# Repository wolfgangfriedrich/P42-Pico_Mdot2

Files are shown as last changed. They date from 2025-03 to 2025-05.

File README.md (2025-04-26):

# P42 Pico M.2

A RPi Pico RP2350A microcontroller board in m.2 3024 form factor with A and E key. The m.2 interface has USB, UART, I2C and control IO connectivity. Voltage levels for the m.2 specification are obeyed as some of the interfaces run on 1.8 V. Externally, +3.3 V, GND, the SWD interface and 16 IOs are accessible on castellated pins. A footprint for a QWIIC connector is on the top side of the board, not populated to have the board as low profile as possible. Power rail LEDs and a user controlled LED is on board, as well as a solder bridge for configuration options. Bottom side has a micro-SD card slot for data storage.
A microcontroller could give any host computer flexible and excellent real-time IO and data processing capabilities. The RPi Pico with its programmable PIO interface has excellent timing resolution. 

### Pre-order campaign on Lectronz https://lectronz.com/campaigns/pre-order-p42-pico2-m-2

Full Feature List:
*	M.2 2230-D5-AE card (22 mm x 30 mm; D5 = 1.5mm on top and bottom side violated by the QWIIC connector and the bottom SD card holder; A and E key)
*	Used interfaces on the M.2: USB, UART, I2C, ALERT, WAKE, DISABLE1/2, LED 1/2, VENDOR_DEFINED
*	1.8V regulator for level-shifters
*	Power LEDs for 3.3 V and 1.1 V
*	RP2040/RP2350 peripherals: 2 MB Flash, SWD debug access, RESET and BOOTSEL button, 
*	QWIIC connector, 1 LED, 1 solder bridge for configuration, 16 GPIOs on castellated pins
*	castellated pins on 25.4 mm/0.1" raster (almost with a 22 mm board)
*	optional uSD card holder on the bottom side
*	optional pull-down resistors on castellated IOs to mitigate the E9 Erratum

Main Components
*	Microcontroller RaspberryPi RP2350A
*	16Mbit QSPI Flash W25Q16
*	12 MHz Crystal SMD_3225-4Pin_3.2x2.5mm
*	MicroSD card holder Molex 104031-0811
*	1.8V-3.3V High Speed level shifter Texas Instruments TXS0102DQM

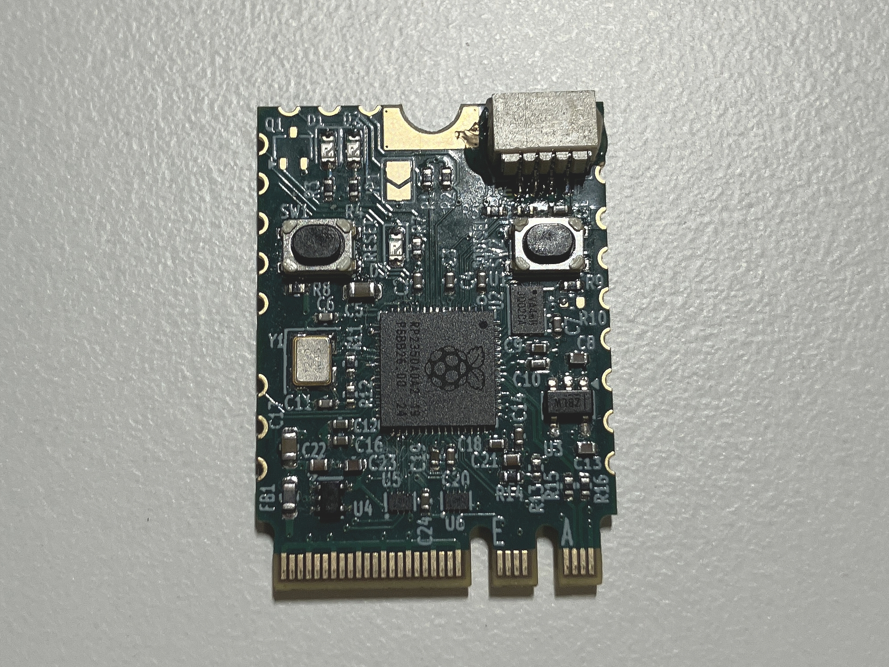
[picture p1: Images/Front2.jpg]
Board Front side


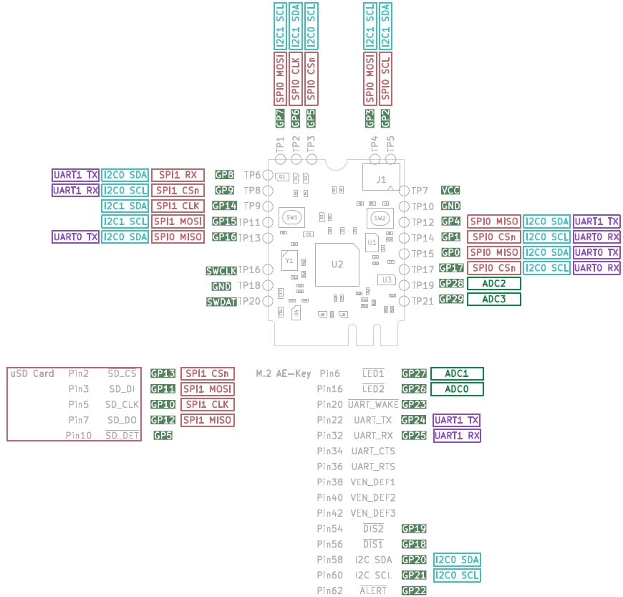
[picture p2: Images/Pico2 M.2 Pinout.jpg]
Board Pinout


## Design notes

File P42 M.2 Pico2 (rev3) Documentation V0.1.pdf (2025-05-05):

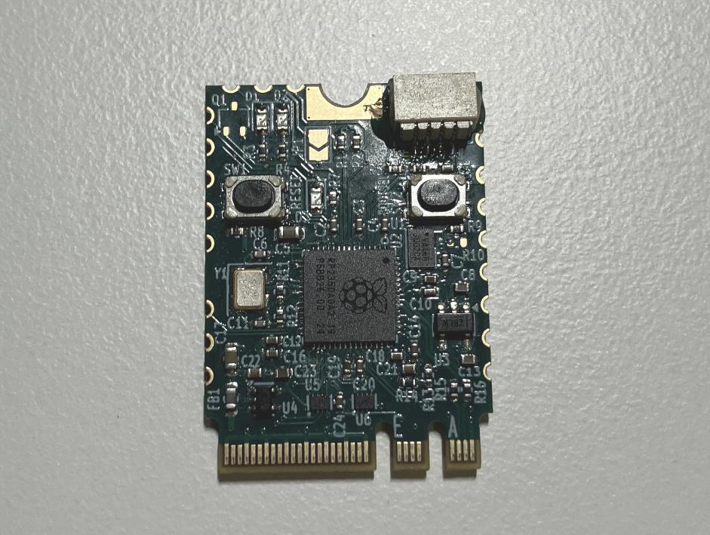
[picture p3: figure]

# P42 Pico2 M.2 Rev 3

Designed by Pier42 Electronics Design Wolfgang Friedrich
Released under CERN Open Hardware License Version 2 - Weakly Reciprocal https://lectronz.com/stores/pier42designhttps://www.tindie.com/stores/pier42/https://hackaday.io/project/199091-rp2040-rp2350-m2-picohttps://github.com/wolfgangfried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

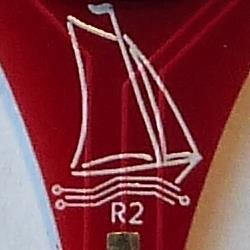
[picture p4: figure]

# Table of Contents

# Introduction

A RPi Pico2 RP2350A microcontroller board in m.2 3024 size form factor with A and E key. The m.2 interface has USB, UART, I2C and control IO connectivity. Voltage levels for the m.2 specification are obeyed as some of the interfaces run on 1.8 V. Externally, +3.3 V, GND, the SWD interface and 16 IOs are accessible on castellated pins. A footprint for a QWIIC connector is on the top side of the board, not populated to have the board as low profile as possible. Power rail LEDs and a user controlled LED is on board, as well as a solder bridge for configuration options. Bottom side has a micro-SD card slot for data storage.
A microcontroller could give any host computer flexible and excellent real-time IO and data processing capabilities. The RPi Pico with its programmable PIO interface has excellent timing resolution.

Full Feature List:
- M.2 2230-D5-AE card (22 mm x 30 mm; D5 = 1.5mm on top and bottom side violated by the QWIIC connector and the bottom SD card holder; A and E key)
- Used interfaces on the M.2: USB, UART, I2C, ALERT, WAKE, DISABLE1/2, LED 1/2, VENDOR_DEFINED
- 1.8V regulator for level-shifters
- Power LEDs for 3.3 V and 1.1 V
- RP2040/RP2350 peripherals: 2 MB Flash, SWD debug access, RESET and BOOTSEL button,
- QWIIC connector, 1 LED, 1 solder bridge for configuration, 16 GPIOs on castellated pins
- castellated pins on 25.4 mm/0.1" raster (almost with a 22 mm board)
- optional µSD card holder on the bottom side
- optional pull-down resistors on castellated IOs to mitigate the E9 Erratum

Main Components
- Microcontroller RaspberryPi RP2350A
- 16Mbit QSPI Flash W25Q16
- 12 MHz Crystal SMD_3225-4Pin_3.2x2.5mm
- MicroSD card holder Molex 104031-0811
- 1.8V-3.3V High Speed level shifter Texas Instruments TXS0102

# Hardware

The board is a standard M.2 2230-D5-AE card (22 mm x 30 mm; 0.8mm thickness; D5 = 1.5mm on top and bottom side violated by the QWIIC connector and the bottom SD card holder; A and E key). The M.2 card edge connector is ENIG plated. Castellated pins are on a 2.54mm (0.1”) raster per side. The mechanical constriants did not work out to have all pins on a global 2.54mm (0.1”) raster.

## Pico2 M.2 Pinout

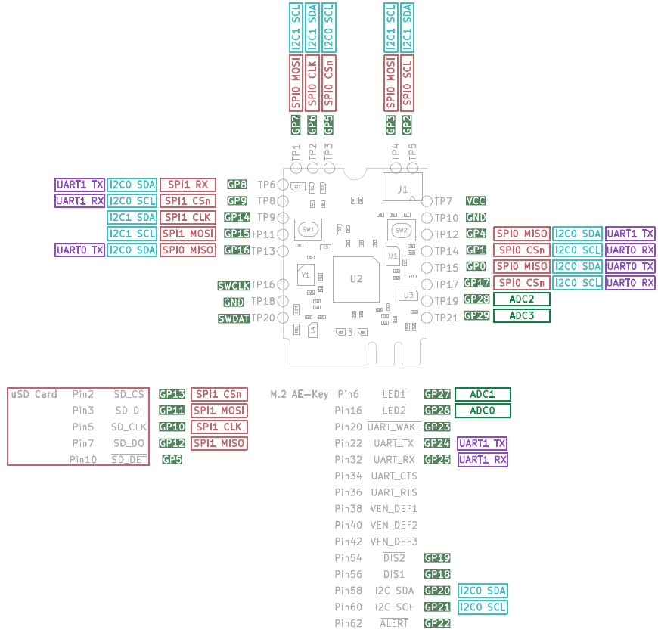
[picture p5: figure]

## M.2 Port Interface

I2C interface on pins 60 (SCL) and 58 (SDA) has address 0x42.
Only the connected pins of this board are listed in this interface table. This is not a full port specification

Pin
Nr
Name | IO | Description | Voltage
1 | GND | Power | Return current path | 0 V
2 | 3.3V | Power | 3.3 V source | 3.3 V
3 | USB+ | IO | USB Data ± Differential serial data interface compliant to the USB 2.0 Specification
4 | 3.3V | Power | 3.3 V source | 3.3 V
5 | USB- | IO | USB Data ± Differential serial data interface compliant to the USB 2.0 Specification
6 | nLED1 | OUT | Open drain, active low signal. These signals are used to allow the add-in card to provide status indicators via LED devices that will be provided by the system. These LED devices should be tied to +3.3V through a current limiting resistor. Current should be limited to 9mA when LED is On. | 3.3 V

7 | GND | Power | Return current path | 0 V
8 | A Key | -
9 | A Key | -
10 | A Key | -
11 | A Key | -
12 | A Key | -
13 | A Key | -
14 | A Key | -
15 | A Key | -
16 | nLED2 | OUT | Open drain, active low signal. These signals are used to allow the add-in card to provide status indicators via LED devices that will be provided by the system. These LED devices should be tied to +3.3V through a current limiting resistor. Current should be limited to 9mA when LED is On.
17 | n.c.
18 | GND | Power | Return current path | 0 V
19 | n.c.
20 | nWAKE | OUT | Sideband Wake. Open Drain, Active Low. Require pull up on the host side (recommended 15K to 100K ) | 3.3 V
21 | n.c.
22 | TxD | OUT | UART Transmit Data connected to RXD on the platform. | 1.8 V
23 | n.c.
24 | E Key | -
25 | E Key | -
26 | E Key | -
27 | E Key | -
28 | E Key | -
29 | E Key | -
30 | E Key | -
31 | E Key | -
32 | RxD | IN | UART Receive Data connected to TXD on the platform. | 1.8 V
33 | GND | Power | Return current path | 0 V
34 | CTS | OUT | Can be connected to RTS through a 0402 resistor footprint. No connection on the module.
35 | n.c.
36 | RTS | IN | Can be connected to CTS through a 0402 resistor footprint. No connection on the module.
37 | n.c.
38 | VEN DEF1 | OUT | May be pulled up to +3.3V through a resistor on the board.
39 | GND | Power | Return current path | 0 V
40 | VEN DEF2 | OUT | May be pulled down to GND through a resistor on the board.
41 | n.c.

Table 1: M.2 Port Interface Pins
1) All IO directions are from the module point of view.
42 | VEN DEF3 | OUT | May be pulled down to GND through a resistor on the board.
43 | n.c.
44 | n.c.
45 | GND | Power | Return current path | 0 V
46 | n.c.
47 | n.c.
48 | n.c.
49 | n.c.
50 | n.c.
51 | GND | Power
52 | n.c.
53 | n.c.

54

nDISABLE2 | IN | Active low, debounced signal when applied by the system it will disable radio operation on the add-in cards that implement radio frequency applications. When implemented, these signals require a pull-up resistor on the card.

3.3 V

55 | n.c.

56

nDISABLE1 | IN | Active low, debounced signal when applied by the system it will disable radio operation on the add-in cards that implement radio frequency applications. When implemented, these signals require a pull-up resistor on the card.

3.3 V

57 | GND | Power | Return current path | 0 V
58 | SDA | IO | I2C data | 3.3 V
59 | n.c.
60 | SCL | IN | I2C clock input from host | 3.3 V
61 | n.c.
62 | nALERT | OUT | IRQ line to host processor; Active Low | 3.3 V
63 | GND | Power | Return current path | 0 V
64 | n.c.
65 | n.c.
66 | n.c.
67 | n.c.
68 | n.c.
69 | GND | Power | Return current path | 0 V
70 | n.c.
71 | n.c.
72 | +3.3V | Power | 3.3 V source | 3.3 V
73 | n.c.
74 | +3.3V | Power | 3.3 V source | 3.3 V
75 | GND | Power | Return current path | 0 V

## Castellated GPIO Pin Interface

## Control/Status Interface

Pin
Nr
Name | IO | RP2350A
GP port

Description

1 | TP1 | GP7 | LED
2 | TP2 | GP6 | EN
3 | TP3 | GP5 | nSD_DET
4 | TP4 | GP3 | QWIIC SCL
5 | TP5 | GP2 | QWIIC SDA
6 | TP6 | GP8
7 | TP7 | - | +3.3 V
8 | TP8 | GP9
9 | TP9 | GP14
10 | TP10 | - | GND
11 | TP11 | GP15
12 | TP12 | GP4
13 | TP13 | GP16
14 | TP14 | GP1
15 | TP15 | GP0
16 | TP16 | SWCLK
17 | TP17 | GP17
18 | TP18 | - | GND
19 | TP19 | GP28 | ADC2
20 | TP20 | SWD
21 | TP21 | GP29 | ADC3
Pin Nr | Name | IO | Description
| EN | IN
| LED | OUT
| SD_DET | IN
| SWCLK
| GND
| SWD

## QWIIC Connector

A right angle QWIIC connector (part number JST SH-SM04B_SRSS_TB 1x4 1mm pitch).

## µSD Card Connector

A Molex 104031-0811 µSD Card adapter, connected though standard SPI (not SDIO), which limits the data transfer rate to ~180 Kbyte/sec.

## RP Pico2 pin-port map

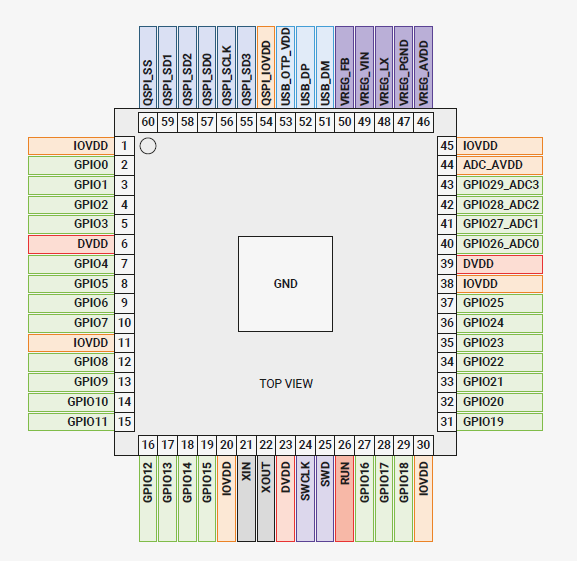
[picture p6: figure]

## Mechanical Dimensions

Pin Nr | Name | IO | Description
1 | GND | Power | Reference return, because ground is where the potatoes grow.
2 | Vcc | Power | +3.3 V
3 | SDA | IO | I2C data signal with 47 KΩ pull-up.
4 | SCL | IO | I2C clock signal with 47 KΩ pull-up.

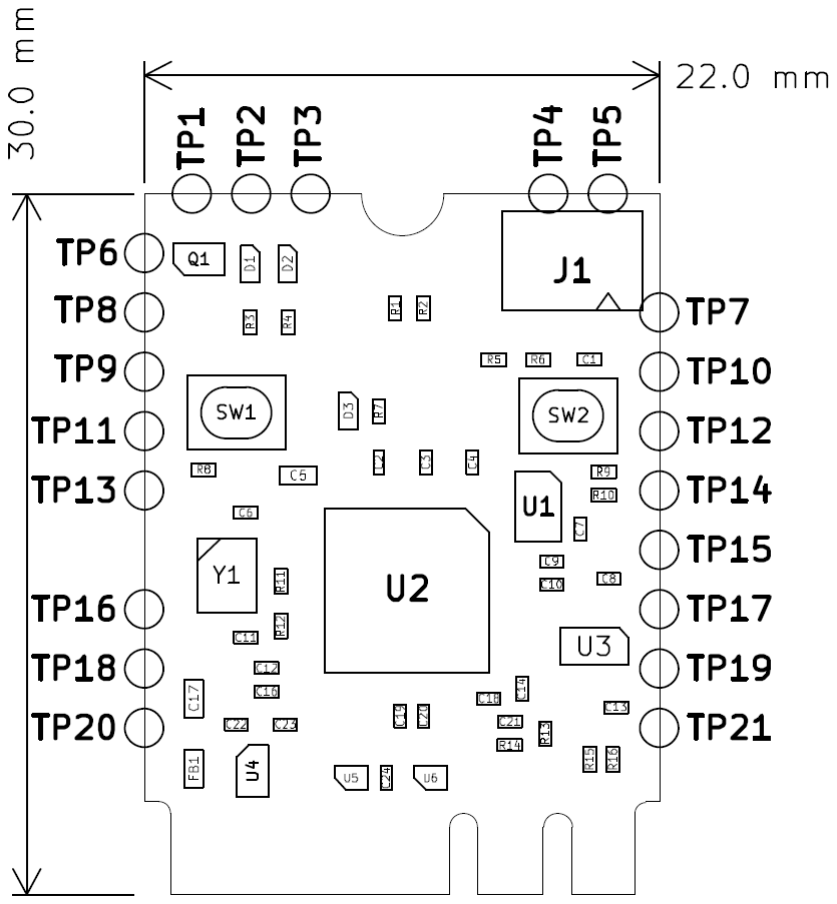
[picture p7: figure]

The SD card holder on the bottom side has a thickness of 1.57mm with inserted SD card. Some M.2 configurations have less clearance on the bottom side. The SD card holder without an inserted card is 1.42mm high.
Also, if the SD card is used together with TP9, TP11, TP13 or TP16; make sure that no solder or wire is protruding on the bottom side, to not interfere with the SD card insertion area.

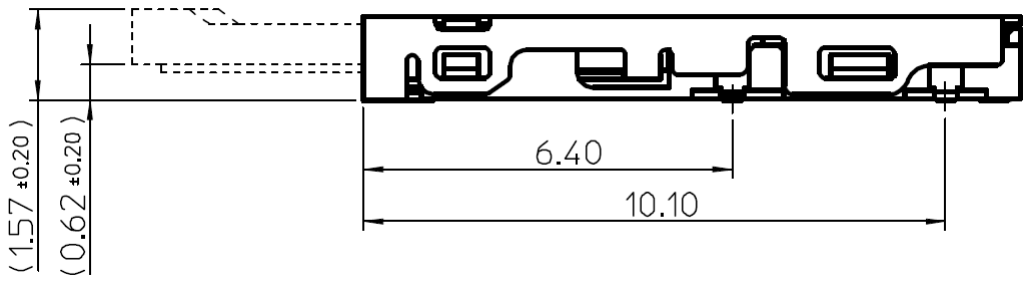
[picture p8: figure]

# Software

A test software is available, it implements a simple command line on the integrated USB-UART port. The source code is written in Arduino and available on the project GitHub.

## Command Description

Command v – Version

Command ? – Help

Command l – LED

Command u – UART

Command I – I2C

Command g – GPIO

Command s – SDcard test

Command d – SDcard directory

Command m – IO pin map

Command t – Test function

# Assembly Drawing

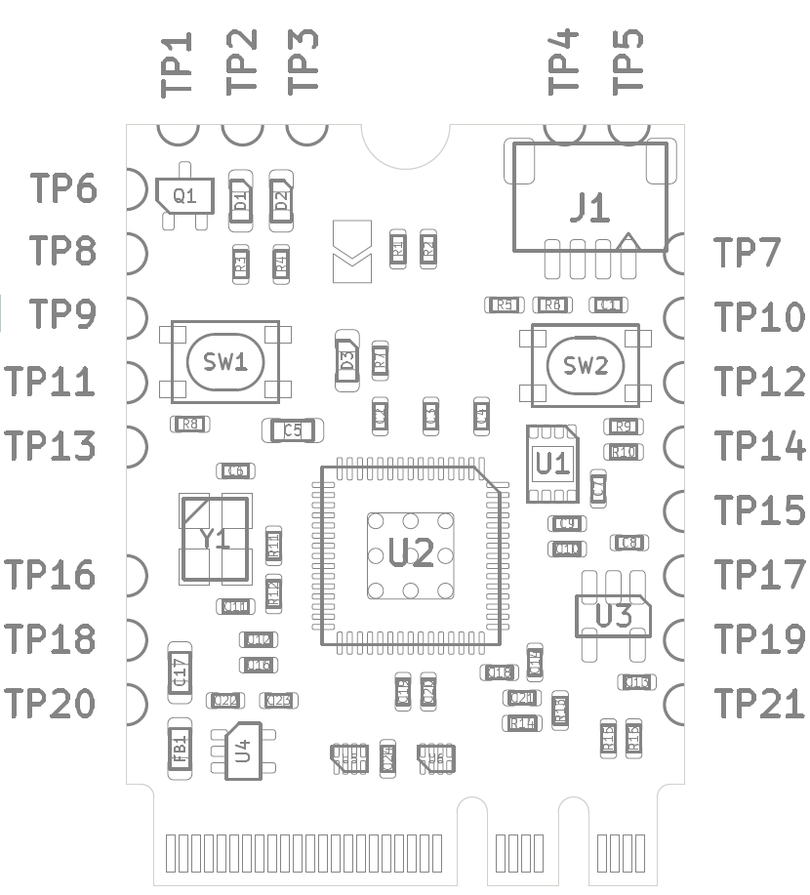
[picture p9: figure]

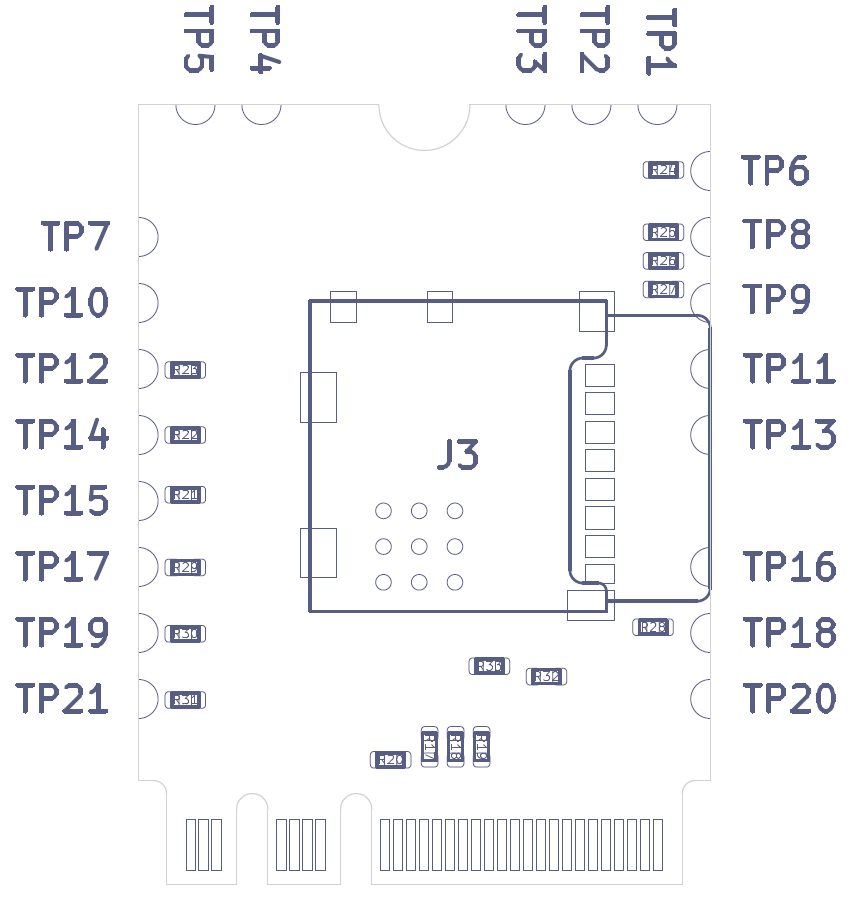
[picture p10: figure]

# Schematics

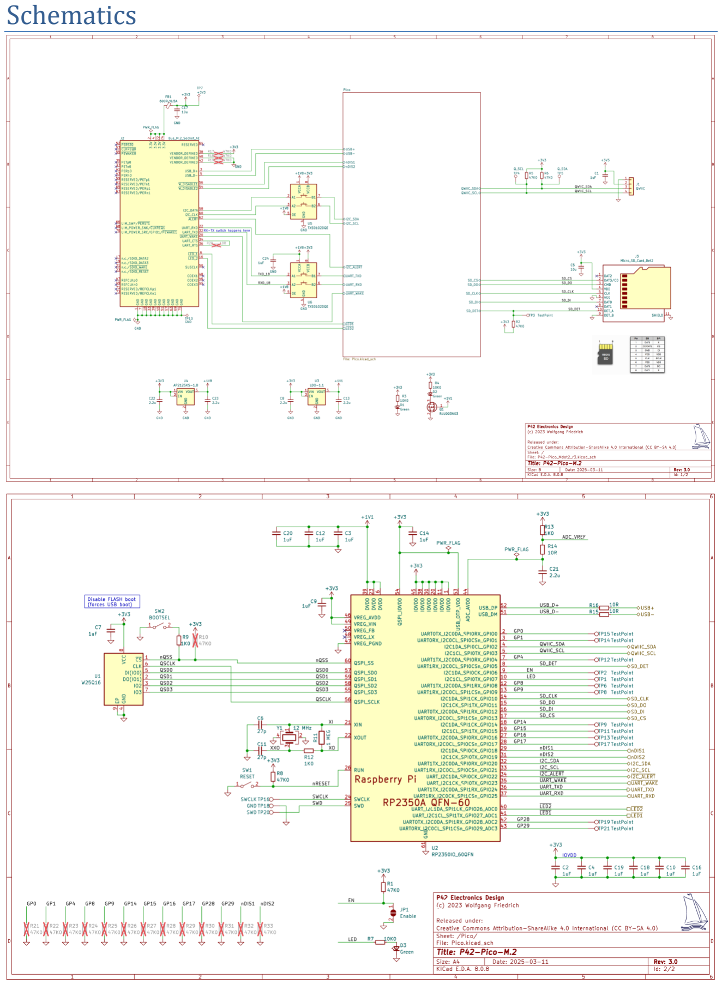
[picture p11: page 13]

# M.2 Pin Reference

This is a living document. Any missing content will be added as required.

# Revision Control

Version | Data | Changes
1.0 | 22. Mar 2025 | Initial Release Rev 3 Madman Chicken-Scratch Manifesto

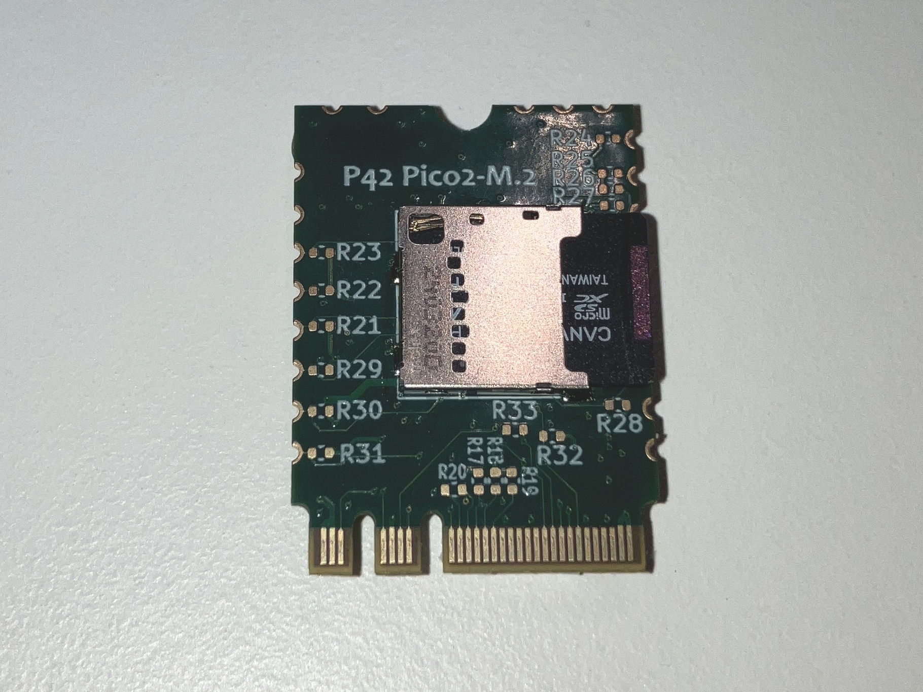
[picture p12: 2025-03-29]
Images/Back2.jpg

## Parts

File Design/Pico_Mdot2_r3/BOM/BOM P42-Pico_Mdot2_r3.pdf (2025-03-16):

# | Qty Reference | Description | Value | DNP JLCPCB # | LCSC Part # LCSC Part #2 Mfr | Mfr PN | Mfr1 | Mfr1 PN | Footprint

1 | 14 C1,C2,C3,C4,C7,C9,C10,C
| 12,C14,C16,C18,C19,C20,
| C24
Cap Cer, 1uF, +-10%, X5R, 25V, 0402 | 1uF | C52923 | C52923 | generic | na | generic | na | Capacitor_SMD:C_0402_1005Metric
2 | 2 C5,C17 | CAP CER 10UF 25V X5R 0603 | 10u | C96446 | C96446 | Samsung | CL31B106KBHNNNE | | | Capacitor_SMD:C_0603_1608Metric
3 | 2 C6,C11 | Cap Cer, 27pF, +-5%, NP0, 0402 | 27p | C1557 | C1557 | generic | na | generic | na | Capacitor_SMD:C_0402_1005Metric
4 | 5 C8,C13,C21,C22,C23 | CAP CER 2.2UF 16V X5R 0402 | 2.2u | C326556 | C326556 | generic | na | generic | na | Capacitor_SMD:C_0402_1005Metric
5 | 3 D1,D2,D3 | LED GREEN CLEAR 0603 SMD | Green | C434420 | C434420 | WÃ¼rth | 150060GS75000 | Yongyu Photoelectric SZYY0603G | LED_SMD:LED_0603_1608Metric
6 | 1 FB1 | IND FERRITE 600R 0.5A 0603 | 600R/0.5A | C710380 | C710380 | Murata | BLM18AG601SN1D | | | Inductor_SMD:L_0603_1608Metric
7 | 1 J1 | CONN HEADER R/A 4POS 1MM SMD | QWIIC | C160404 | C160404 | JST | SH_SM04B-SRSS-TB | JST | SM04B-SRSS-TB(LF)(SN) Connector_JST:JST_SH_SM04B-SRSS-TB_1x04-1MP_P1.00mm_Horizontal
8 | 1 J2 | | Bus_M.2_Socket_AE | | | | | | | NGFF:NGFF_A+E
9 | 1 J3 | CONN MICRO SD CARD PUSH-PULL R/A | Micro_SD_Card_Det2 | C585350 | C585350 | | | | | Connector_Card:microSD_HC_Molex_104031-0811
10 | 1 Q1 | MOSFET N-CH 30V 300MA SC70-3 | RJU003N03 | C5336707 C5336707 | Rohm | RJU003N03FRAT106 | Package_TO_SOT_SMD:SOT-323_SC-70
11 | 1 R11 | Res, 1MEG, 1%, 0.625W, 0402 | 1 MEG | C25741 | C25741 | generic | na | generic | na | Resistor_SMD:R_0402_1005Metric
12 | 1 R20 | Res, 10R, 1%, 0.625W, 0402 | 10R | DNP C25077 | C25077 | generic | na | generic | na | Resistor_SMD:R_0402_1005Metric
13 | 5 R1,R2,R5,R6,R8 | Res, 47K0, 1%, 0.625W, 0402 | 47K0 | C25900 | C25900 | generic | na | generic | na | Resistor_SMD:R_0402_1005Metric
14 | 17 R10,R17,R18,R19,R21,R2
| 2,R23,R24,R25,R26,R27,R
| 28,R29,R30,R31,R32,R33 | Res, 47K0, 1%, 0.625W, 0402 | 47K0 | DNP C25900 | C25900 | generic | na | generic | na | Resistor_SMD:R_0402_1005Metric
15 | 3 R14,R15,R16 | Res, 10R, 1%, 0.625W, 0402 | 10R | C25077 | C25077 | generic | na | generic | na | Resistor_SMD:R_0402_1005Metric
16 | 3 R3,R4,R7 | Res, 10K0, 1%, 0.625W, 0402 | 10K0 | C25744 | C25744 | generic | na | generic | na | Resistor_SMD:R_0402_1005Metric
17 | 3 R9,R12,R13 | Res, 1K0, 1%, 0.625W, 0402 | 1K0 | C11702 | C11702 | generic | na | generic | na | Resistor_SMD:R_0402_1005Metric
18 | 1 SW1 | Switch Tact, SPST-NO, PTS810 Series, SMD | RESET | C19724063 C19724063 C470427 | C&K | PTS810 SJS 250 SMTR LFS | ALPSALPINE | SKRPAME010 | Button_Switch_SMD:SW_SPST_PTS810
19 | 1 SW2 | Switch Tact, SPST-NO, PTS810 Series, SMD | BOOTSEL | C19724063 C19724063 C470427 | C&K | PTS810 SJS 250 SMTR LFS | ALPSALPINE | SKRPAME010 | Button_Switch_SMD:SW_SPST_PTS810
26 | 1 U1 | IC, Flash, SPI, 16 MBit, USON-8 | W25Q16 | C2843335 C2843335 | Winbond | W25Q16JVUXIQ | Winbond | W25Q16JLUXIG diff pad Package_SON:SON-8-1EP_3x2mm_P0.5mm_EP1.4x1.6mm
27 | 1 U2 | IC MCU 32BIT EXT MEMQFN-60 | RP2350IO_60QFN | C42411118 C42411118 | RP2350_60QFN:RP2350-QFN-60-1EP_7x7_P0.4mm_EP3.4x3.4mm_ThermalVias
28 | 1 U3 | IC REG LINEAR 1.1V 300MA SOT23-5 | LDO-1.1 | C2865431 C2865431 | C485147 | Texas Instruments TLV73311PDBVR | Texas Instruments | TLV74311PDBVR | Package_TO_SOT_SMD:SOT-23-5
29 | 1 U4 | IC REG LINEAR 1.8V 300MA SC70-5 | AP2125KS-1.8 | C7214645 C7214645 | C53149 | Diodes Inc. | AP2125KS-1.8TRG1 | TI | TLV70018DCKT | Package_TO_SOT_SMD:SOT-353_SC-70-5
30 | 2 U5,U6 | IC TRANSLTR BIDIRECTIONAL 8SON | TXS0102DQE | C2652935 C2652935 | TI | TXS0102DQER | Package_SON:X2SON-8_1.4x1mm_P0.35mm
31 | 1 Y1 | CRYSTAL 12.0MHZ 18PF 20PPM SMD-4 | 12 MHz | C9002 | C9002 | Raltron | RH100-12.000-18-2020-EXT-TR | Crystal:Crystal_SMD_3225-4Pin_3.2x2.5mm

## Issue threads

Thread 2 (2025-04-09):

Broken link + Thinkpad + CircuitPython

dglaude, 2025-04-09:
I got a 404 on https://lectronz.com/seller/campaigns/pre-order-p42-pico2-m-2

Also, will that work on the slot in a Thinkpad 440p?

Do you have plan to create a CircuitPython board definition?

dglaude, 2025-04-09:
https://lectronz.com/campaigns/pre-order-p42-pico2-m-2
Seems to be the right URL... I need to compare both to see if there is a typo.

wolfgangfriedrich, 2025-04-09:
Thanks for notifying me about the broken link. It is fixed now. Your link suggestion was correct.

I found a sales website that claims, the M.2 slot in the 440p is a B key 2242 size, so the card will not fit there.

I have not worked with CricuitPython at all, but you sparked my interest now. However this activity would not happend before the campaign is fulfilled. A standard Pico2 board definition might work, one just needs to be careful with certain IOs that have a fixed function on the board.

Cheers, - W.

Closed 2025-04-09.

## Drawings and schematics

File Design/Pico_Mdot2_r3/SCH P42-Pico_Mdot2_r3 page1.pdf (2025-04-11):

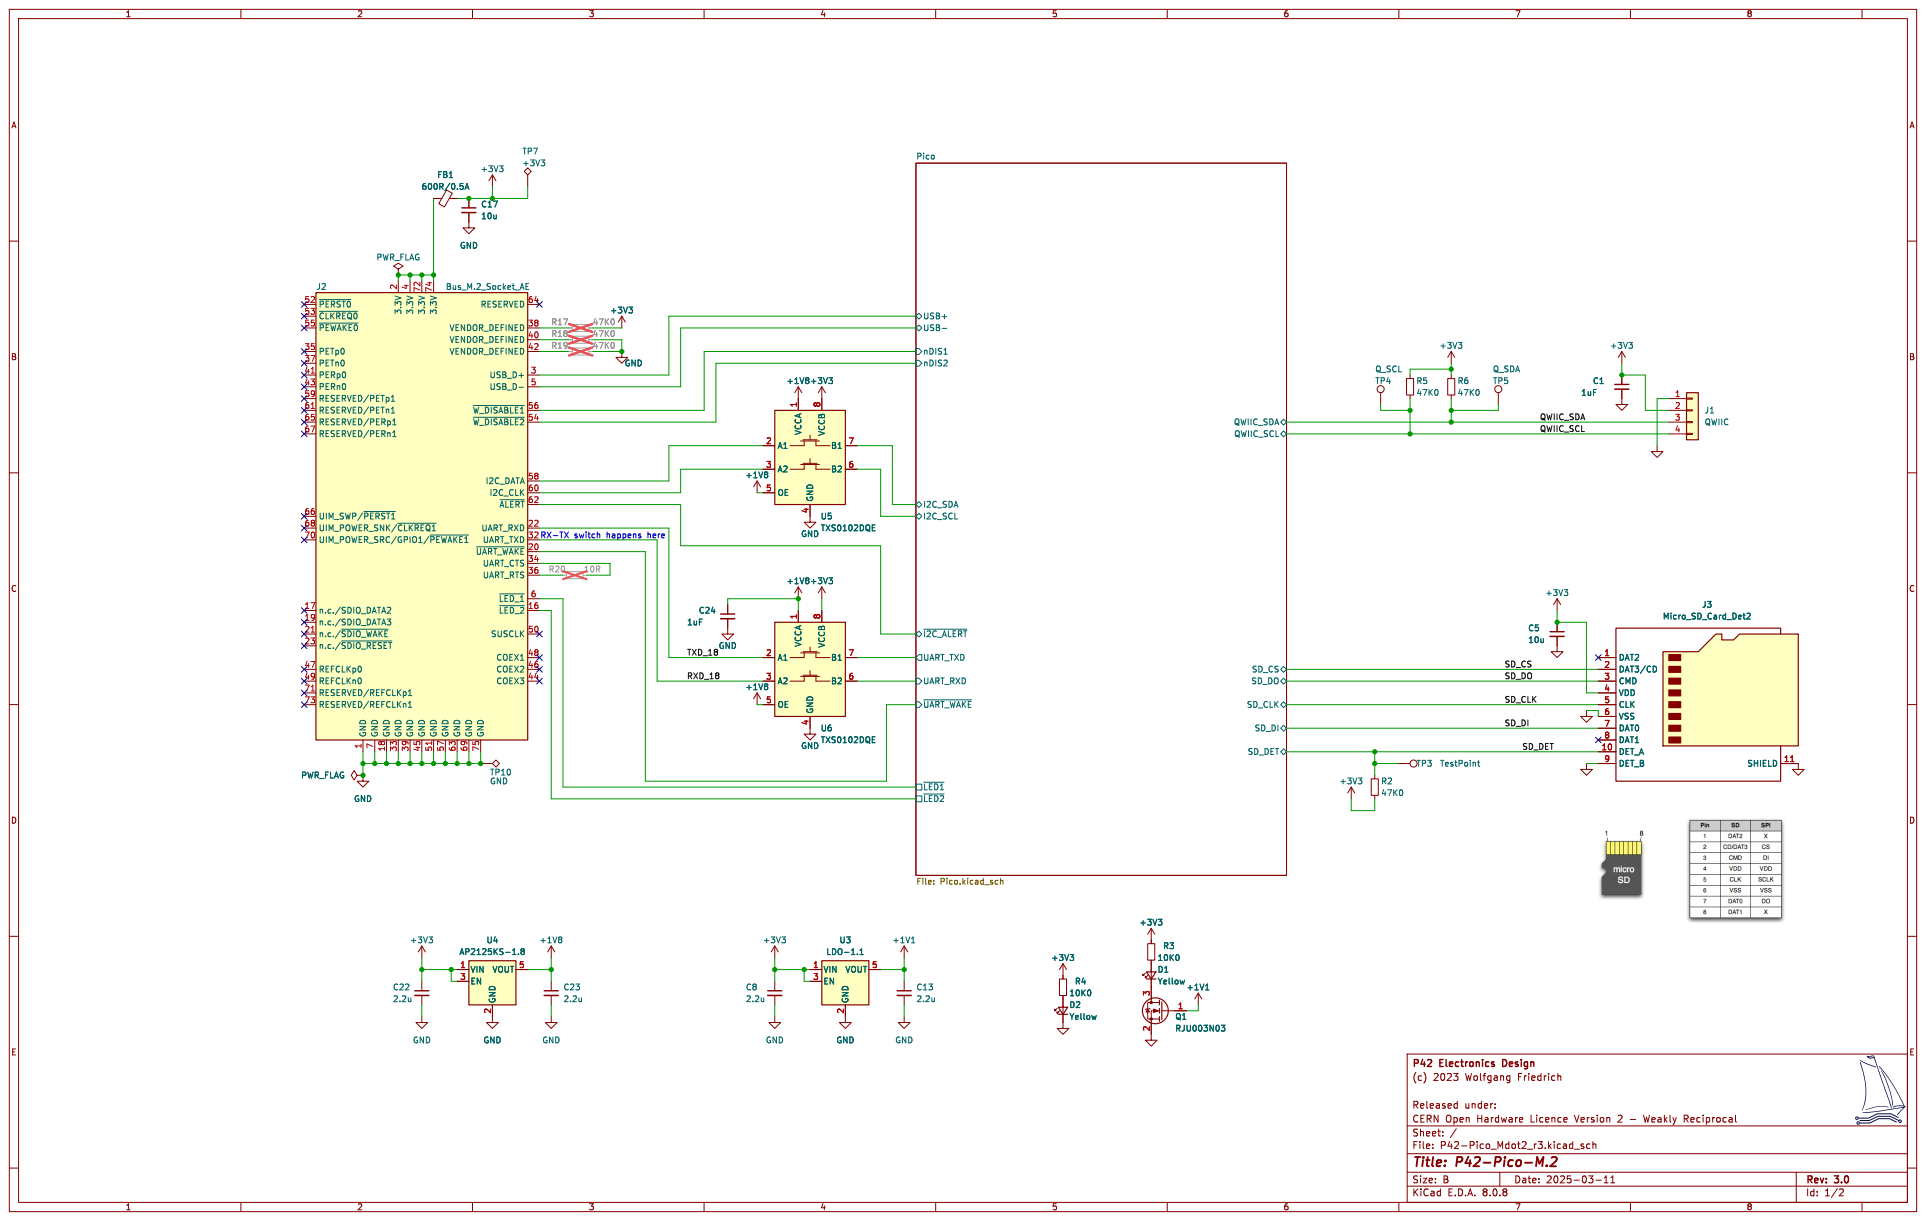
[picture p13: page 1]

SD_DET QWIIC_SCL SD_DI SD_CS RX-TX switch happens here C17

4 VENDOR_DEFINED 40 PERp0 41 VENDOR_DEFINED 42 PERn0 43 COEX3 44 GND 45 COEX2 46 REFCLKp0 47 COEX1 48 REFCLKn0 49 USB_D- 5 SUSCLK 50 GND 51 ~{PERST0} 52 ~{CLKREQ0} 53 ~{W_DISABLE2}54 ~{PEWAKE0} 55 ~{W_DISABLE1}56 GND 57

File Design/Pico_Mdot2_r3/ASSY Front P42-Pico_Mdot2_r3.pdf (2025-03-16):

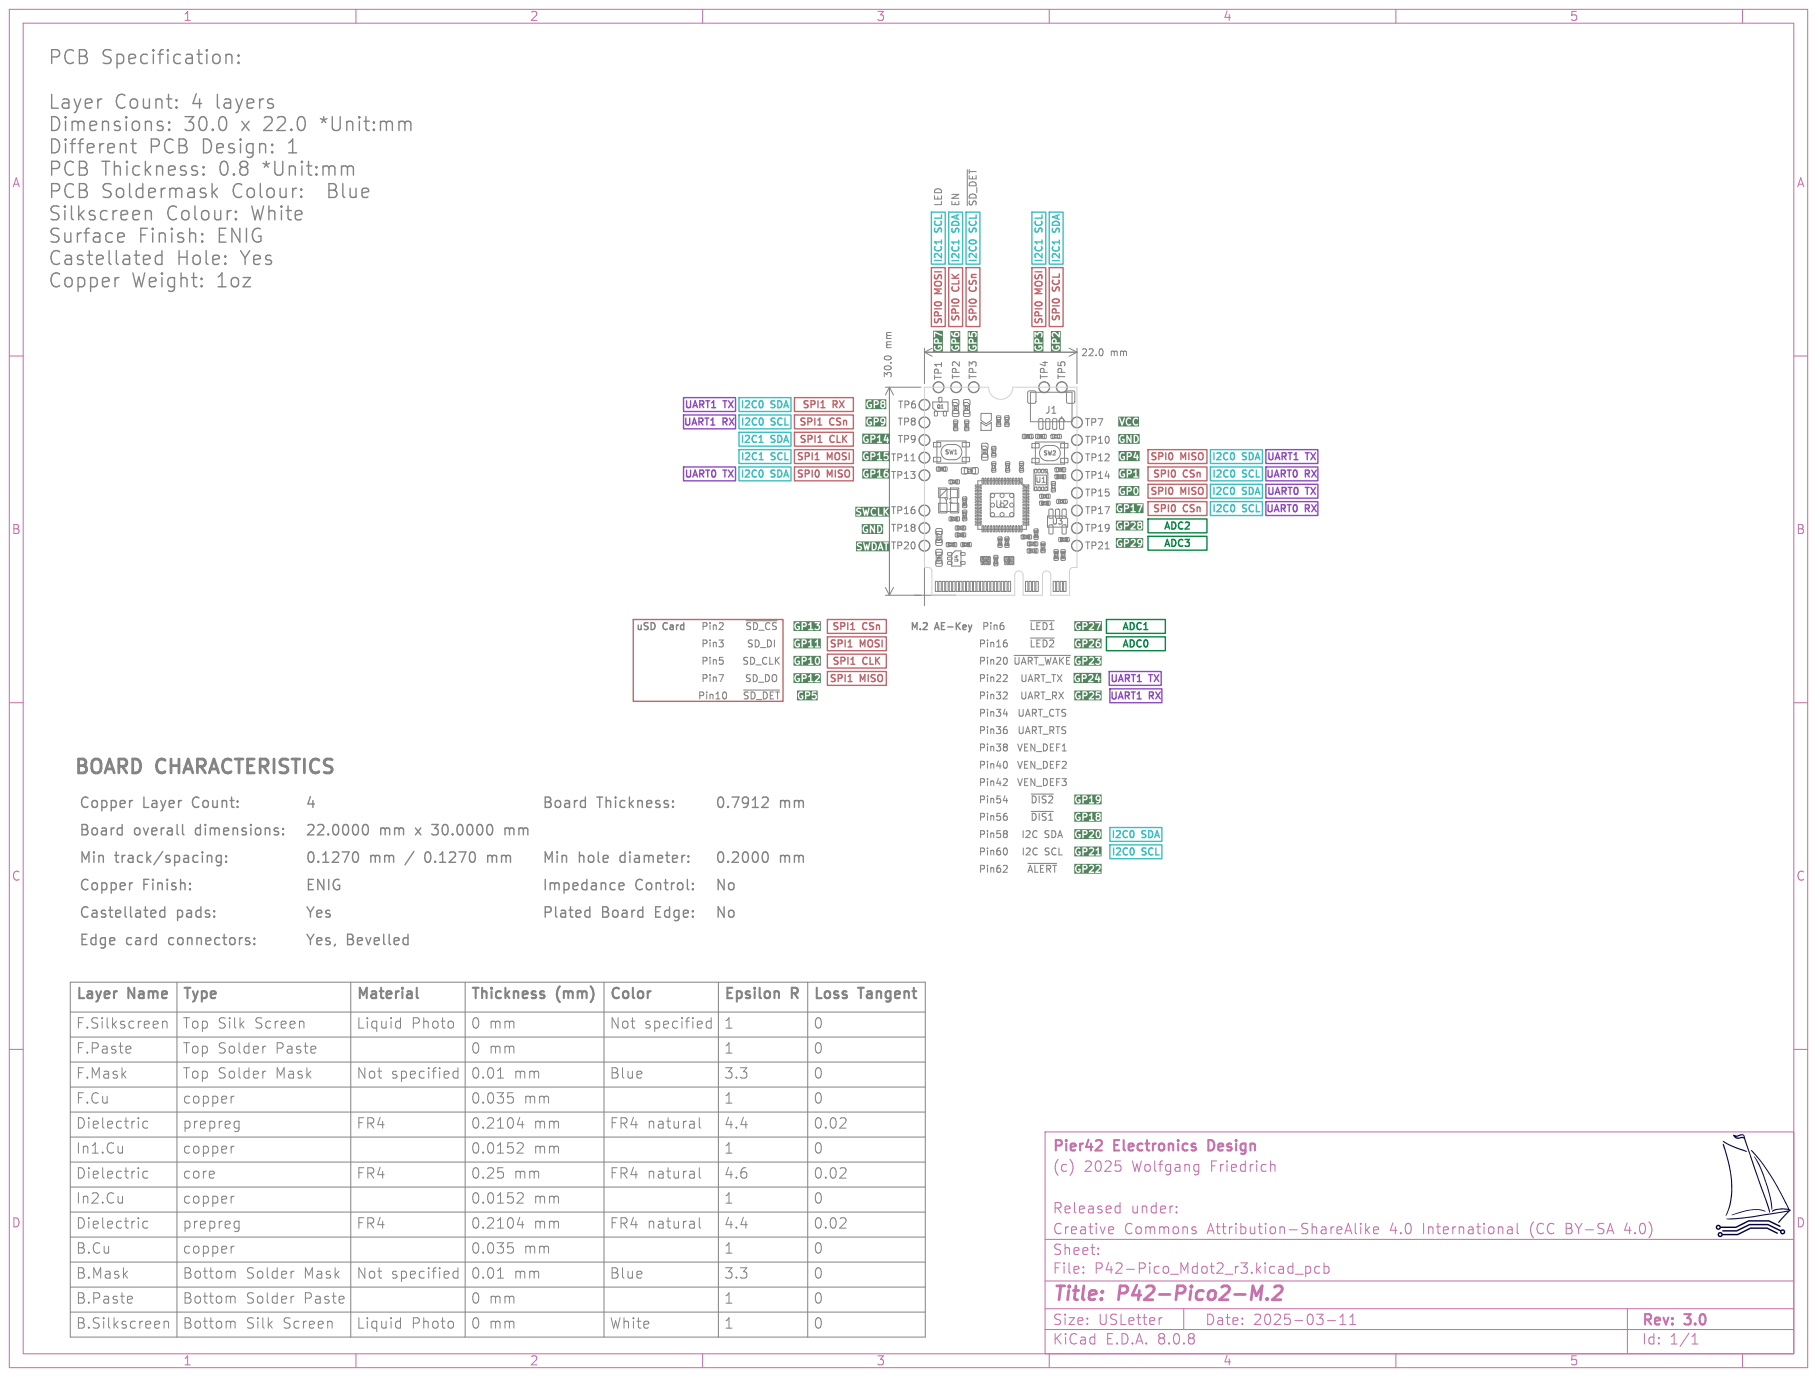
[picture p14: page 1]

1 FR4 natural Top Solder Paste Copper Finish: PCB Specification:

Layer Count: 4 layers
PCB Thickness: 0.8 *Unit:mm
Surface Finish: ENIG
Copper Weight: 1oz

Loss Tangent 3.3 Plated Board Edge:

copper Top Silk Screen

1 Blue Bottom Silk Screen

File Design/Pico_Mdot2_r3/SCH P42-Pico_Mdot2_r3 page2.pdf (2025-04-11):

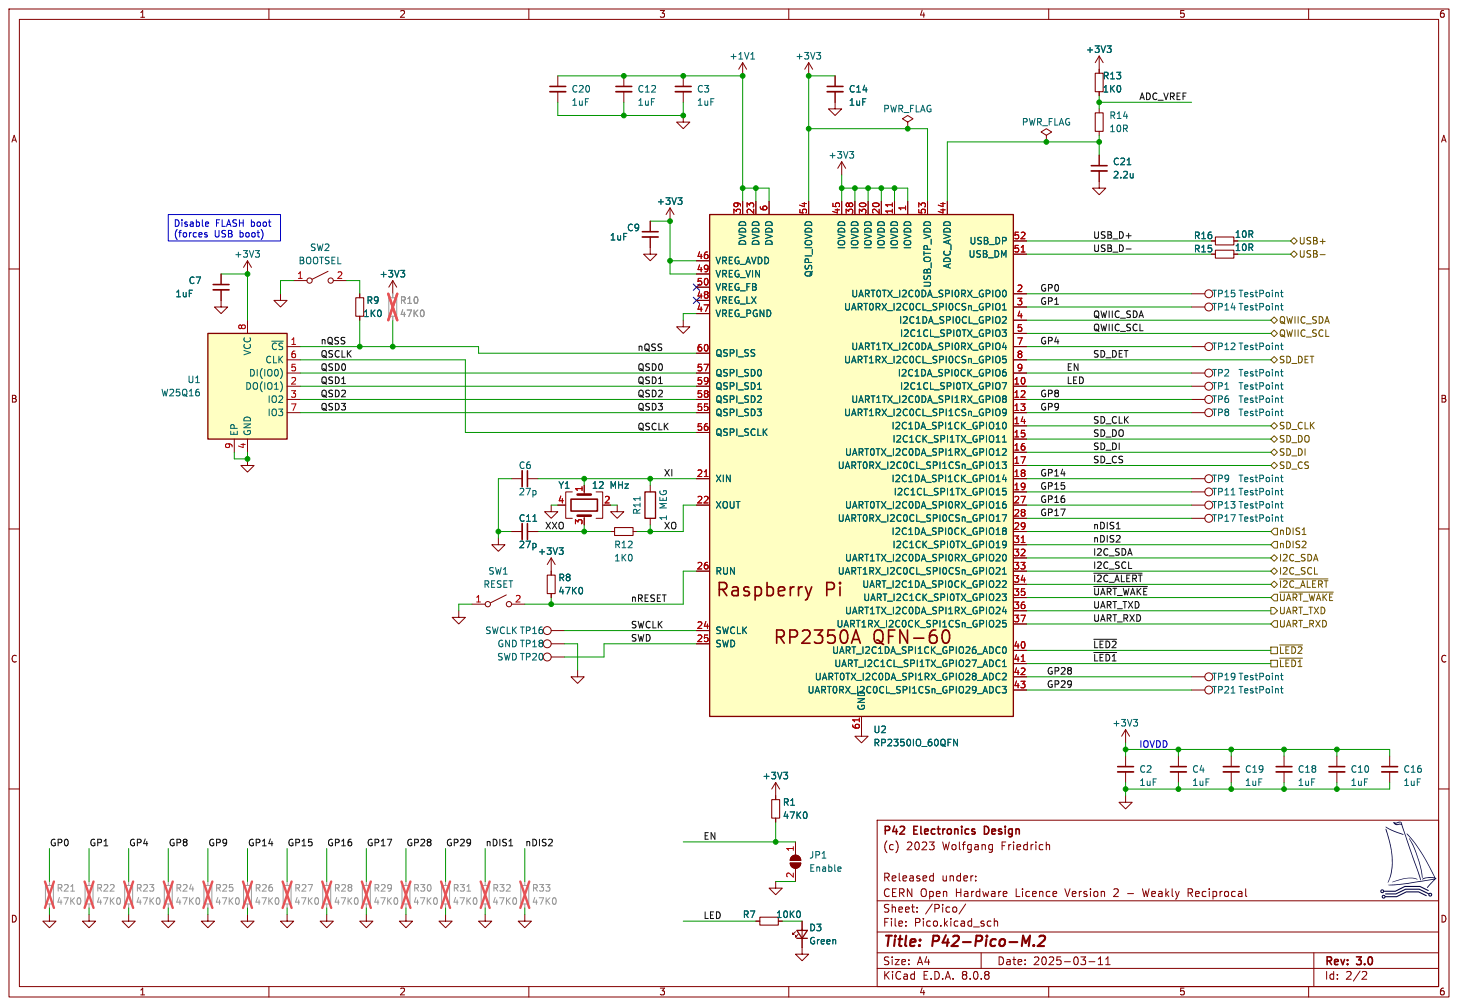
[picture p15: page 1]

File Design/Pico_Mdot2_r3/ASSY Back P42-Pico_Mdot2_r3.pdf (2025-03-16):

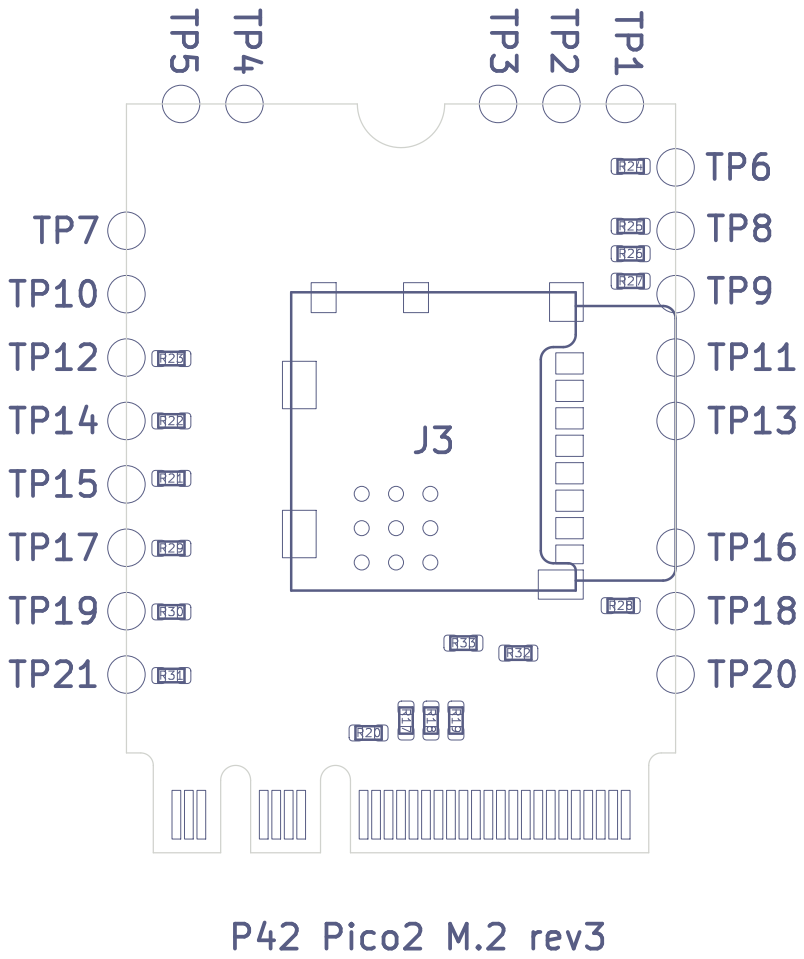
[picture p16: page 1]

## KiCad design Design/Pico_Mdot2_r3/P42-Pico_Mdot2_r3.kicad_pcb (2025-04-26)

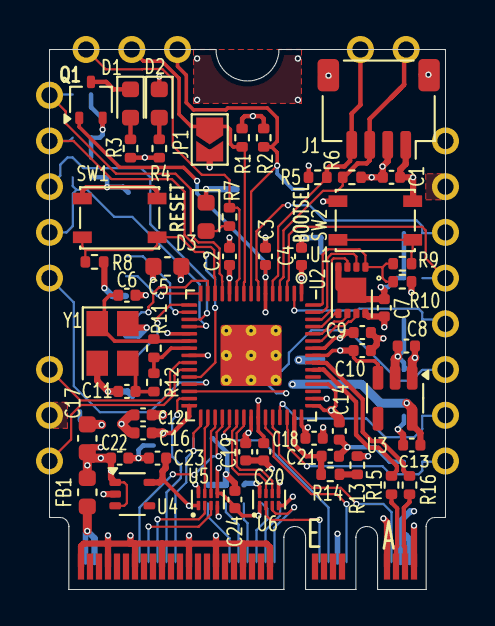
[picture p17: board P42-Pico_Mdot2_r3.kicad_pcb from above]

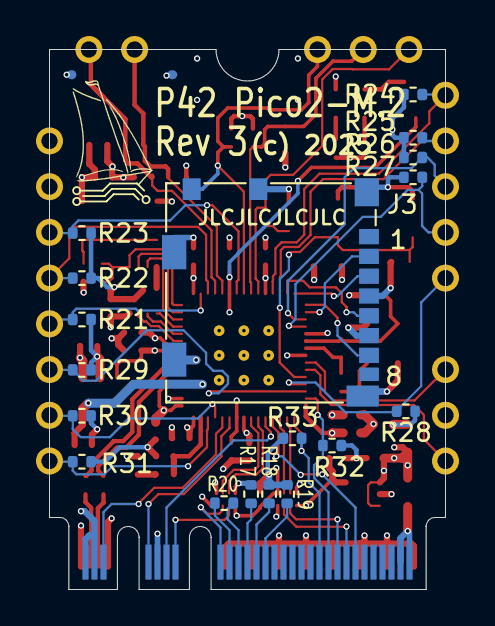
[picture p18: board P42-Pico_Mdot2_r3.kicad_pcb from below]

Board: 4 copper layers, 22.0 x 30.0 mm, 95 parts (18 on the bottom side), 67 nets.

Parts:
C1, C2, C3, C4, C7, C9, C10, C12, C14, C16, C18, C19, C20, C24: 1uF; C_0402_1005Metric
C5, C17: 10u; C_0603_1608Metric
C6, C11: 27p; C_0402_1005Metric
C8, C13, C21, C22, C23: 2.2u; C_0402_1005Metric
D1, D2: Yellow; LED_0603_1608Metric
D3: Green; LED_0603_1608Metric
FB1: 600R/0.5A; L_0603_1608Metric
J1: QWIIC; JST_SH_SM04B-SRSS-TB_1x04-1MP_P1.00mm_Horizontal
J2: Bus_M.2_Socket_AE; NGFF_A+E
J3: Micro_SD_Card_Det2; microSD_HC_Molex_104031-0811
JP1: Enable; SolderJumper-2_P1.3mm_Open_TrianglePad1.0x1.5mm
Q1: RJU003N03; SOT-323_SC-70
R1, R2, R5, R6, R8, R10, R17, R18, R19, R21, R22, R23, R24, R25, R26, R27, R28, R29, R30, R31, R32, R33: 47K0; R_0402_1005Metric
R3, R4, R7: 10K0; R_0402_1005Metric
R9, R12, R13: 1K0; R_0402_1005Metric
R11: 1 MEG; R_0402_1005Metric
R14, R15, R16, R20: 10R; R_0402_1005Metric
SW1: RESET; SW_SPST_PTS810
SW2: BOOTSEL; SW_SPST_PTS810
TP1, TP2, TP3, TP6, TP8, TP9, TP11, TP12, TP13, TP14, TP15, TP17, TP19, TP21: TestPoint; THTPad_D1.5mm_Drill0.9mm
TP4: Q_SCL; THTPad_D1.5mm_Drill0.9mm
TP5: Q_SDA; THTPad_D1.5mm_Drill0.9mm
TP7: +3V3; THTPad_D1.5mm_Drill0.9mm
TP10, TP18: GND; THTPad_D1.5mm_Drill0.9mm
TP16: SWCLK; THTPad_D1.5mm_Drill0.9mm
TP20: SWD; THTPad_D1.5mm_Drill0.9mm
U1: W25Q16; SON-8-1EP_3x2mm_P0.5mm_EP1.4x1.6mm
U2: RP2350IO_60QFN; RP2350-QFN-60-1EP_7x7_P0.4mm_EP3.4x3.4mm_ThermalVias
U3: LDO-1.1; SOT-23-5
U4: AP2125KS-1.8; SOT-353_SC-70-5
U5, U6: TXS0102DQE; X2SON-8_1.4x1mm_P0.35mm
Y1: 12 MHz; Crystal_SMD_3225-4Pin_3.2x2.5mm

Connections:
+1V1: C3.1, C12.1, C13.1, C20.1, Q1.1 (G), U2.6 (DVDD), U2.23 (DVDD), U2.39 (DVDD), U3.5 (VOUT)
+1V8: C23.1, C24.1, U4.5 (VOUT), U5.1 (VCCA), U5.5 (OE), U6.1 (VCCA), U6.5 (OE)
+3V3: C1.1, C2.1, C4.1, C5.1, C7.1, C8.1, C9.1, C10.1, C14.1, C16.1, C17.1, C18.1, C19.1, C22.1, FB1.1, J1.2, J3.4 (VDD), R1.2, R2.1, R3.1, R4.1, R5.2, R6.2, R8.2, R10.2, R13.2, R17.1, TP7.1, U1.8 (VCC), U2.1 (IOVDD), U2.11 (IOVDD), U2.20 (IOVDD), U2.30 (IOVDD), U2.38 (IOVDD), U2.45 (IOVDD), U2.46 (VREG_AVDD), U2.49 (VREG_VIN), U2.53 (USB_OTP_VDD), U2.54 (QSPI_IOVDD), U3.1 (VIN), U3.3 (EN), U4.1 (VIN), U4.3 (EN), U5.8 (VCCB), U6.8 (VCCB)
/Pico/ADC_VREF: R13.1, R14.2
/Pico/EN: JP1.1 (A), R1.1, TP2.1, U2.9 (I2C1DA_SPI0CK_GPIO6)
/Pico/GP0: R21.2, TP15.1, U2.2 (UART0TX_I2C0DA_SPI0RX_GPIO0)
/Pico/GP1: R22.2, TP14.1, U2.3 (UART0RX_I2C0CL_SPI0CSn_GPIO1)
/Pico/GP4: R23.2, TP12.1, U2.7 (UART1TX_I2C0DA_SPI0RX_GPIO4)
/Pico/GP8: R24.2, TP6.1, U2.12 (UART1TX_I2C0DA_SPI1RX_GPIO8)
/Pico/GP9: R25.2, TP8.1, U2.13 (UART1RX_I2C0CL_SPI1CSn_GPIO9)
/Pico/GP14: R26.2, TP9.1, U2.18 (I2C1DA_SPI1CK_GPIO14)
/Pico/GP15: R27.2, TP11.1, U2.19 (I2C1CL_SPI1TX_GPIO15)
/Pico/GP16: R28.2, TP13.1, U2.27 (UART0TX_I2C0DA_SPI0RX_GPIO16)
/Pico/GP17: R29.2, TP17.1, U2.28 (UART0RX_I2C0CL_SPI0CSn_GPIO17)
/Pico/GP28: R30.2, TP19.1, U2.42 (UART0TX_I2C0DA_SPI1RX_GPIO28_ADC2)
/Pico/GP29: R31.2, TP21.1, U2.43 (UART0RX_I2C0CL_SPI1CSn_GPIO29_ADC3)
/Pico/I2C_SCL: U2.33 (UART1RX_I2C0CL_SPI0CSn_GPIO21), U5.6 (B2)
/Pico/I2C_SDA: U2.32 (UART1TX_I2C0DA_SPI0RX_GPIO20), U5.7 (B1)
/Pico/LED: R7.1, TP1.1, U2.10 (I2C1CL_SPI0TX_GPIO7)
/Pico/QSCLK: U1.6 (CLK), U2.56 (QSPI_SCLK)
/Pico/QSD0: U1.5 (DI(IO0)), U2.57 (QSPI_SD0)
/Pico/QSD1: U1.2 (DO(IO1)), U2.59 (QSPI_SD1)
/Pico/QSD2: U1.3 (IO2), U2.58 (QSPI_SD2)
/Pico/QSD3: U1.7 (IO3), U2.55 (QSPI_SD3)
/Pico/SWCLK: TP16.1, U2.24 (SWCLK)
/Pico/SWD: TP20.1, U2.25 (SWD)
/Pico/UART_RXD: U2.37 (UART1RX_I2C0CK_SPI1CSn_GPIO25), U6.6 (B2)
/Pico/UART_TXD: U2.36 (UART1TX_I2C0DA_SPI1RX_GPIO24), U6.7 (B1)
/Pico/USB+: J2.3 (USB_D+), R16.1
/Pico/USB-: J2.5 (USB_D-), R15.1
/Pico/USB_D+: R16.2, U2.52 (USB_DP)
/Pico/USB_D-: R15.2, U2.51 (USB_DM)
/Pico/XI: C6.1, R11.1, U2.21 (XIN), Y1.1
/Pico/XO: R11.2, R12.2, U2.22 (XOUT)
/Pico/XXO: C11.1, R12.1, Y1.3
/Pico/nDIS1: J2.56 (~W_DISABLE1), R32.2, U2.29 (I2C1DA_SPI0CK_GPIO18)
/Pico/nDIS2: J2.54 (~W_DISABLE2), R33.2, U2.31 (I2C1CK_SPI0TX_GPIO19)
/Pico/nQSS: R9.1, R10.1, U1.1 (~CS), U2.60 (QSPI_SS)
/Pico/nRESET: R8.1, SW1.2 (B), U2.26 (RUN)
/Pico/~I2C_ALERT: J2.62 (~ALERT), U2.34 (UART_I2C1DA_SPI0CK_GPIO22)
/Pico/~LED1: J2.6 (~LED_1), U2.41 (UART_I2C1CL_SPI1TX_GPIO27_ADC1)
/Pico/~LED2: J2.16 (~LED_2), U2.40 (UART_I2C1DA_SPI1CK_GPIO26_ADC0)
/Pico/~UART_WAKE: J2.20 (~UART_WAKE), U2.35 (UART_I2C1CK_SPI0TX_GPIO23)
/QWIIC_SCL: J1.4, R5.1, TP4.1, U2.5 (I2C1CL_SPI0TX_GPIO3)
/QWIIC_SDA: J1.3, R6.1, TP5.1, U2.4 (I2C1DA_SPI0CL_GPIO2)
/RXD_18: J2.32 (UART_TXD), U6.3 (A2)
/SD_CLK: J3.5 (CLK), U2.14 (I2C1DA_SPI1CK_GPIO10)
/SD_CS: J3.2 (DAT3/CD), U2.17 (UART0RX_I2C0CL_SPI1CSn_GPIO13)
/SD_DET: J3.10 (DET_A), R2.2, TP3.1, U2.8 (UART1RX_I2C0CL_SPI0CSn_GPIO5)
/SD_DI: J3.7 (DAT0), U2.16 (UART0TX_I2C0DA_SPI1RX_GPIO12)
/SD_DO: J3.3 (CMD), U2.15 (I2C1CK_SPI1TX_GPIO11)
/TXD_18: J2.22 (UART_RXD), U6.2 (A1)
GND: C1.2, C2.2, C3.2, C4.2, C5.2, C6.2, C7.2, C8.2, C9.2, C10.2, C11.2, C12.2, C13.2, C14.2, C16.2, C17.2, C18.2, C19.2, C20.2, C21.2, C22.2, C23.2, C24.2, D2.1 (K), D3.1 (K), J1.1, J2.1 (GND), J2.7 (GND), J2.18 (GND), J2.33 (GND), J2.39 (GND), J2.45 (GND), J2.51 (GND), J2.57 (GND), J2.63 (GND), J2.69 (GND), J2.75 (GND), J3.6 (VSS), J3.9 (DET_B), J3.11 (SHIELD), JP1.2 (B), Q1.2 (S), R18.1, R19.1, R21.1, R22.1, R23.1, R24.1, R25.1, R26.1, R27.1, R28.1, R29.1, R30.1, R31.1, R32.1, R33.1, SW1.1 (A), SW2.1 (A), TP10.1, TP18.1, U1.4 (GND), U1.9 (EP), U2.47 (VREG_PGND), U2.61 (GND), U3.2 (GND), U4.2 (GND), U5.4 (GND), U6.4 (GND), Y1.2, Y1.4
unnamed: D1.2 (A), R3.2
unnamed: D1.1 (K), Q1.3 (D)
unnamed: D2.2 (A), R4.2
unnamed: D3.2 (A), R7.2
unnamed: FB1.2, J2.2 (3.3V), J2.4 (3.3V), J2.72 (3.3V), J2.74 (3.3V)
unnamed: J2.60 (I2C_CLK), U5.3 (A2)
unnamed: J2.58 (I2C_DATA), U5.2 (A1)
unnamed: J2.34 (UART_CTS), R20.1
unnamed: J2.36 (UART_RTS), R20.2
unnamed: J2.38 (VENDOR_DEFINED), R17.2
unnamed: J2.40 (VENDOR_DEFINED), R18.2
unnamed: J2.42 (VENDOR_DEFINED), R19.2
unnamed: R9.2, SW2.2 (B)
unnamed: C21.1, R14.1, U2.44 (ADC_AVDD)

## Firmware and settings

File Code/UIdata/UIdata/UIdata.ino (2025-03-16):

#include <Arduino.h>
#include <Wire.h>


void setup() {



  // put your setup code here, to run once:

	Serial.begin(19200);

delay(2000);
  Serial.println("\r\nP42 Pico M.2 Serial1 Wire Tester");

//!!!!! M.2 Pico - NOT Pico2 !!!!!
#define M2_UART_TXD   16
#define M2_UART_RXD   17

  Serial1.setTX(M2_UART_TXD);  
  Serial1.setRX(M2_UART_RXD);
  Serial1.begin(19200);
  Serial1.println("P42 Pico M.2 UART1");

//!!!!! M.2 Pico - NOT Pico2 !!!!!
#define M2_I2C_SDA    20
#define M2_I2C_SCL    21

  Wire.setSDA(M2_I2C_SDA);
//Serial.print(".");
  Wire.setSCL(M2_I2C_SCL);
//Serial.print(".");
  Wire.begin(40); // join i2c bus (address optional for master)
  // Wire.setClock(100000);

Wire.onReceive(receiveEvent); // register event

I2C_scan();

}


void receiveEvent(int howMany)
{
  while(1 < Wire.available()) // loop through all but the last
  {
    char c = Wire.read(); // receive byte as a character
    Serial.print(c);         // print the character
  }
  int x = Wire.read();    // receive byte as an integer
  Serial.println(x);         // print the integer
}




void loop() {
  // put your main code here, to run repeatedly:
uint8_t   b_IncomingByte = 0;   // for incoming serial data
uint8_t   i;

i++;

	while (Serial1.available() != 0) {
		b_IncomingByte = Serial1.read();
    Serial.print( (char) b_IncomingByte );
  }

Serial1.println("M.2 UART data");

        Wire.beginTransmission(0x42);  // transmit to device #4
        Wire.write("M.2 I2C 3.1)");         // sends bytes, last on is printed ASCII code!
        Wire.endTransmission();     // stop transmitting

Serial.print(".");

	delay(5000);    // wait for serial port to be configured

}


//----------------------------------------------------------------------
uint8_t I2C_scan()
{
  byte error, address;
  int nDevices;
 
  Serial.println("Scanning...");
 
  nDevices = 0;
  for(address = 1; address < 127; address++ )
  {
    // The i2c_scanner uses the return value of
    // the Write.endTransmisstion to see if
    // a device did acknowledge to the address.
    Wire.beginTransmission(address);
    error = Wire.endTransmission();
 
    if (error == 0)
    {
      Serial.print("I2C device found at address 0x");
      if (address<16)
        Serial.print("0");
      Serial.print(address,HEX);
      Serial.println("  !");
 
      nDevices++;
    }
    else if (error==4)
    {
      Serial.print("Unknown error at address 0x");
      if (address<16)
        Serial.print("0");
      Serial.println(address,HEX);
    }    
  }
  if (nDevices == 0)
    Serial.println("No I2C devices found\n");
  else
    Serial.println("done\n");

  return nDevices;
 
}

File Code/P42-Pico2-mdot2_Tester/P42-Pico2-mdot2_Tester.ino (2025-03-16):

/*
  Tester

  Testing all functions of the P42-Pico2-m.2 board
  
  Version
  0.1: 27. Jan 2025
       Moved code to RP2350 Pico2 board
  0.2: 11. Mar 2025
       Added proper I2C command: bus scan
       Test function is data write and read from I2C EEPROM 24C02
	   
*/
#include <Arduino.h>
#include <Wire.h>
// for SD card
#include <SPI.h>
#include <SD.h>
#include "tools.h"
#include "P42-Pico2-mdot2.h"

//uint8_t TPs[] = {TP1, TP2, TP3, TP4, TP5, TP6, TP8, TP10, TP11, TP12, TP13, TP14, TP15, TP17, TP19, TP21 };
uint8_t TPs[] = {TP1, TP2, TP6, TP8, TP9, TP11, TP12, TP13, TP14, TP15, TP17, TP19, TP21 }; // Rev 2 without QWIIC and Serial2
// uint8_t TPs[] = {TP1, TP2 }; // test

uint32_t start_time = 0;
uint32_t current_time = 0;
bool SDcard_present = false;
File root;





// the setup function runs once when you press reset or power the board
void setup() {

uint32_t i;

	current_time = millis();
	start_time = current_time;

	Serial.begin(19200);
  Serial.setTimeout(10000);   // set timeout to 10 sec
	//Terminal program need local echo now!
	delay(1000);    // wait for serial port to be configured

	Serial.println("");
	Serial.print(F("P42 Pico2 M.2 Tester"));
	Serial.println(PICO_MDOT2_VERSION);

  // Board IOs
 	pinMode(LED, OUTPUT);
  digitalWrite( LED, HIGH );
 	pinMode(ENABLE, INPUT);

Serial.println(F(" [OK] Board GPIO config done."));

// Serial config
// UART0 in schematic is Serial1 in code
// UART1 in schematic is Serial2 in code

  // assign pin numbers for Serial2
  Serial2.setTX(M2_UART_TXD);  
  Serial2.setRX(M2_UART_RXD);
  Serial2.begin(19200);
  Serial2.println("P42 Pico M.2 UART1");

//Serial2.setTX(TX2);  
//Serial2.setRX(RX2);
//Serial2.begin(19200);    // slow baud rate to make the transfer visible on DMM
//Serial2.println("P42 Pico M.2 UART2");

Serial.println(F(" [OK] Serial config done."));


// I2C config
// I2C0 in schematic is Wire in code
// I2C1 in schematic is Wire1 in code
  Wire1.setSDA(QWIIC_SDA);
  Wire1.setSCL(QWIIC_SCL);
  Wire1.begin(); // join i2c bus as master
  // Serial.print(".");
  Wire1.onReceive(receiveEvent1); // register event


  Wire.setSDA(M2_I2C_SDA);
//Serial.print(".");
  Wire.setSCL(M2_I2C_SCL);
//Serial.print(".");
  // Wire.begin(I2C_ADR); // join i2c bus (address optional for master)
  Wire.begin(); // join i2c bus (address optional for master)
//Serial.print(".");
Wire.onReceive(receiveEvent); // register event

  Serial.println(F(" [OK] I2C config done."));


// M.2 Signals
pinMode (N_UART_WAKE, OUTPUT);
digitalWrite(N_UART_WAKE, HIGH);
pinMode (N_I2C_ALERT, OUTPUT);
digitalWrite(N_I2C_ALERT, HIGH);
pinMode (N_LED1, INPUT);
pinMode (N_LED2, INPUT);
pinMode (N_DISABLE1, INPUT_PULLUP);
pinMode (N_DISABLE2, INPUT_PULLUP);

Serial.println(F(" [OK] M.2 GPIO config done."));

// uSD card
SPI1.setRX(SD_DI);
SPI1.setCS(SD_CS);
SPI1.setSCK(SD_CLK);
SPI1.setTX(SD_DO );

Serial.print(F(" SPI config SPI1 /"));
Serial.print(F(" SPI CS: "));
Serial.print(SD_CS);
Serial.print(F(" / SPI CLK: "));
Serial.print(SD_CLK);
Serial.print(F(" / SPI DO: "));
Serial.print(SD_DO);
Serial.print(F(" / SPI DI: "));
Serial.println(SD_DI);

pinMode (SD_DETECT, INPUT_PULLUP);

if ( digitalRead(SD_DETECT) == HIGH) {
  Serial.println(F(" [!!] No uSD card present!"));
  SDcard_present = false;
}
else {
  Serial.println(F(" [OK] SDcard config done."));
  // https://github.com/earlephilhower/arduino-pico/discussions/925
  sd_cardInit();
  sd_cardInfo();
  root = SD.open("/");
  printDirectory(root, 0);

  SDcard_present = true;

  // for exFAT cards, use:
  // https://github.com/greiman/SdFat
}
//  sd_cardInit();

	Serial.print(F("Config done. READY.\n\r>") );
  digitalWrite( LED, LOW );

}

 // the loop function runs over and over again forever until it doesn't
void loop() {

uint32_t  i,j, result;
uint8_t   b_IncomingByte = 0;   // for incoming serial data

char cmd[32];
char pin = 0xff;
char c;

  if (!SDcard_present && (digitalRead(SD_DETECT) == LOW) ) {
    SDcard_present = true;
    sd_cardInit();
    Serial.print(">");
  }
  else if (SDcard_present && (digitalRead(SD_DETECT) == HIGH)) {
    SDcard_present = false;
    Serial.println(F("uSD Card removed!"));
    Serial.print(">");
  }

	while (Serial2.available() != 0) {
		b_IncomingByte = Serial2.read();
    Serial.print((char)b_IncomingByte);

  }

	if (Serial.available() != 0) {

		//b_IncomingByte = Serial.read();
     result = Serial.readBytesUntil(13, cmd, 31); 
     cmd[result] = 0;     // terminate


		switch (cmd[0]) {

			case CMD_LED:
        // Serial.print(CMD_LED);
				// read next byte 
				//while (Serial.available() == 0) {};
				//b_IncomingByte = Serial.read();
        pinMode(LED, OUTPUT);

        if (cmd[1] == '0') {
          Serial.println("0\r\nLED off");
          digitalWrite( LED, LOW );
        }
        else if (cmd[1] == '1') {
          Serial.println("1\r\nLED on");
          digitalWrite( LED, HIGH );
        }
        else {
          Serial.println("\r\nBad argument. Try again!");
        };

			break;

			case CMD_VERSION:
        //Serial.print(CMD_VERSION);
				Serial.print(F("\r\nPier42 Pico2 M.2 (c) "));
				Serial.print(PICO_MDOT2_VERSION_DATE);
				Serial.println(PICO_MDOT2_VERSION);
			break;

			case CMD_HELP:
        //Serial.print(CMD_HELP);
				Serial.println(F("\r\nl[0/1] Turn LED on or off"));
				Serial.println(F("v      Show Version"));
				Serial.println(F("u      UART test - M.2 TX RX - UART1 loopback"));
				Serial.println(F("i[0/1] I2C bus scan"));
				Serial.print(F("g[0.."));
        c = sizeof(TPs)+'A'-11;
        Serial.print(c);
//        Serial.print((char)sizeof(TPs)+'A'-11);
        Serial.println(F("][0/1] GPIOs go tooooogle."));
				Serial.println(F("s      uSD card test"));
				Serial.println(F("d      uSD card root directory"));
				Serial.println(F("m      Scan all M.2 Interface GPIOs"));
				Serial.println(F("t      runs unspecified test code"));
				Serial.println(F("?      This help command"));
			break;

			case CMD_UART:
      // Serial1 is M.2 UART port connected to  external USB-UART adapter 
      // Keys entered in the external USB-UART adapter before entering the 'u' command in the Tester terminal will be displayed. 
      // FIFO size = 16 bytes
        //Serial.println(CMD_UART);

				// Serial.println(F("\r\nSerial1:"));
//        Serial1.flush(); // not a loopback so no flush() allowed to display character that are received.
        // Serial1.println("[OK] Test Serial1.");
        delay (100);    // wait 10msec for some data to arrive
				// while (Serial1.available() != 0) {
				  // b_IncomingByte = Serial1.read();
          // Serial.write(b_IncomingByte);
        // };
        // some subcommands:
        // loopback: send something and expect the same back
        // send cmd to expect ascii '0'-'9' back
        // send cmd to expect 0x55 0xaa 0xaf 0xfe back
        // send cmd to expect 0xc0 0xff 0xee back
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

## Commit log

2025-03-16 Initial data commit
    Design, Code, Documentation
    [P42-Pico_Mdot2_r3.kicad_sch, Pico.kicad_sch]
2025-03-16 Delete Code/P42-Pico-mdot2_Tester directory
    only good for rev 1 with RP2040
2025-03-16 Create BOM P42-Pico_Mdot2_r3.pdf
2025-04-03 Update P42-Pico_Mdot2_r3.kicad_sch
    Changed power LEDs to yellow
    [P42-Pico_Mdot2_r3.kicad_sch]
2025-04-11 SCH update with license
    .kicad_sch sources and PDF docs.
    [P42-Pico_Mdot2_r3.kicad_sch, Pico.kicad_sch]
2025-04-11 Update README.md
    Added images of board and pinout
2025-04-26 Sales units ready
    Up test FW to rev1.0
    Release PCB layout
    [P42-Pico_Mdot2_r3.kicad_pcb]

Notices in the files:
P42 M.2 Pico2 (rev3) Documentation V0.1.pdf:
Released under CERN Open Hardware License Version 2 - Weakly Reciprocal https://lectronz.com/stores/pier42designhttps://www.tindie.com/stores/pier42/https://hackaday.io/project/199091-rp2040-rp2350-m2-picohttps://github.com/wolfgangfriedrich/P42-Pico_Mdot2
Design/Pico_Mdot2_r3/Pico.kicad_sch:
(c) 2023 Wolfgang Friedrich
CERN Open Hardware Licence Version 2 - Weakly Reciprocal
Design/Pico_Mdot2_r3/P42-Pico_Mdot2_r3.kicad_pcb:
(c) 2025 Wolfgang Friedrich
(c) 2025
